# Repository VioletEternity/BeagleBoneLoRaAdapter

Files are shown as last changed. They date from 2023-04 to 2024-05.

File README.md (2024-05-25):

# Dual LoRa module adapter for BeagleBone

This PCBA connects widely available LoRa modules based on Semtech [SX127x][] RFIC, such as [this module][module] ([archive][module-archive]) sold on Aliexpress for less than $3, to the Texas Instruments [BeagleBone][] family of single board computers.

[module]: https://www.aliexpress.com/item/32814250318.html
[module-archive]: https://archive.today/oJ4Fh
[sx127x]: https://www.semtech.com/products/wireless-rf/lora-connect
[beaglebone]: https://beaglebone.org

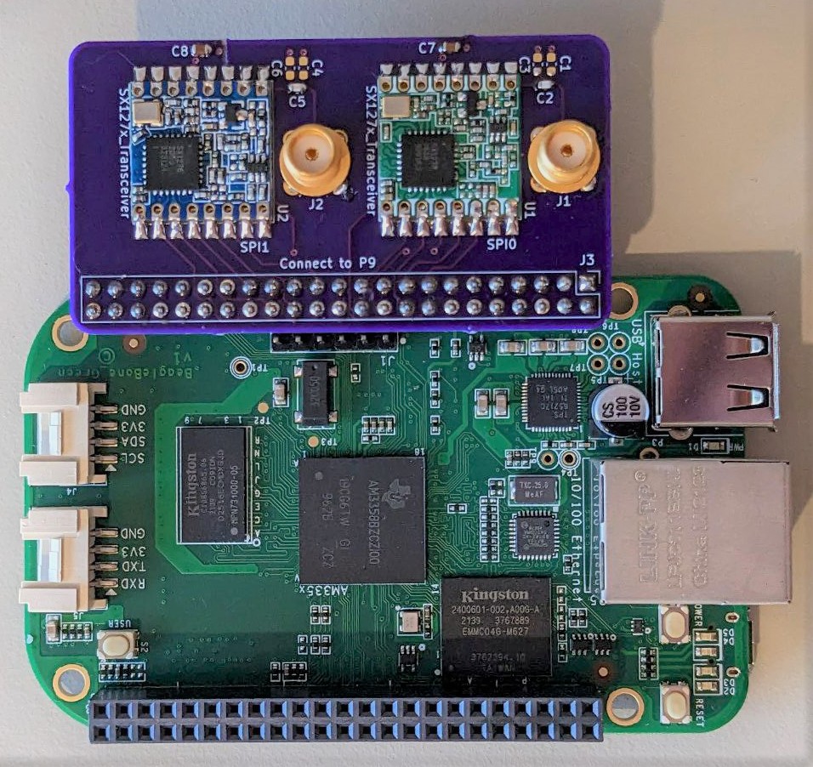
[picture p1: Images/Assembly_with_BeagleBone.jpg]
assembled board


## Requirements

The module must have a size of 16 by 16 mm, and have 16 castellated pads with 2 mm spacing; for details, see the Kicad footprint. The module pinout must match the following, viewed from the top:

| Pin 1? | &nbsp;&nbsp;&nbsp;&nbsp;&nbsp;&nbsp;&nbsp;&nbsp;&nbsp;&nbsp;&nbsp;&nbsp;&nbsp;&nbsp;&nbsp;&nbsp;&nbsp;&nbsp;&nbsp;&nbsp;&nbsp;&nbsp;&nbsp;&nbsp;&nbsp;&nbsp;&nbsp;&nbsp;&nbsp;&nbsp;&nbsp;&nbsp;&nbsp; | &nbsp; |
| --- | - | --- |
| ANT | | GND |
| GND | | DIO5 |
| DIO3 | | nRESET |
| DIO4 | | nCS |
| 3V3 | | SCK |
| DIO0 | | MOSI |
| DIO1 | | MISO |
| DIO2 | | GND |

These modules do not have a clearly marked pin 1, so the actual pinout may be rotated 180° compared to the above.

See also the [bill of materials](Mfg_Outputs/BeagleBoneLoRaAdapter.csv).

## Usage

### BeagleBone pinout

The following table lists the BeagleBone pins and their connections:

| Radio# | Function | BB pin | CPU pin | 
|---|---|---|---|
| radio0 | nRESET | P9_15  | gpio1[16] |
| radio0 | IRQ | P9_16  | gpio1[19] |
| radio0 | nCS | P9_17  | gpio0[5]  |
| radio0 | SCK | P9_22  | gpio0[2]  |
| radio0 | MOSI | P9_18  | gpio0[4]  |
| radio0 | MISO | P9_21  | gpio0[3]  |
| radio1 | nRESET | P9_25  | gpio3[21] |
| radio1 | IRQ | P9_27  | gpio3[19] |
| radio1 | nCS | P9_28  | gpio3[17] |
| radio1 | SCK | P9_31  | gpio3[14] |
| radio1 | MOSI | P9_30  | gpio3[16] |
| radio1 | MISO | P9_29  | gpio3[15] |

Radio 0 is connected to CS0 of SPI0, radio 1 is connected to CS0 of SPI1.

### BeagleBone pin mux configuration

To configure BeagleBone pins, run the following commands:

```shell
sudo modprobe spidev
sudo chown $USER /dev/spidev*

config-pin P9_15 gpio_pu
config-pin P9_16 gpio_pu
config-pin P9_17 spi_cs
config-pin P9_22 spi_sclk
config-pin P9_18 spi
config-pin P9_21 spi

config-pin P9_25 gpio_pu
config-pin P9_27 gpio_pu
config-pin P9_28 spi_cs
config-pin P9_31 spi_sclk
config-pin P9_30 spi
config-pin P9_29 spi
```

These commands were tested on Debian 12 (bookworm).

### Basic functional test

To perform a basic test of module functionality, install `spi-tools` and run the following commands:

```shell
echo '0: 4200' | xxd -r | spi-pipe -b 2 -d /dev/spidev0.0 | xxd
echo '0: 4200' | xxd -r | spi-pipe -b 2 -d /dev/spidev1.0 | xxd
```

Both commands should return the following output:

```
00000000: 0012                                     ..
```

The number `12` is the module ASIC revision.

### Full functional test

Steps for performing a full test of module functionality, including radio transmission and reception, will be provided later.

## Revision history

A1
: Initial revision

## Terms of distribution

The adapter is covered by the CERN-OHL-P (permissive) license. See [LICENSE.txt](LICENSE.txt) for details.

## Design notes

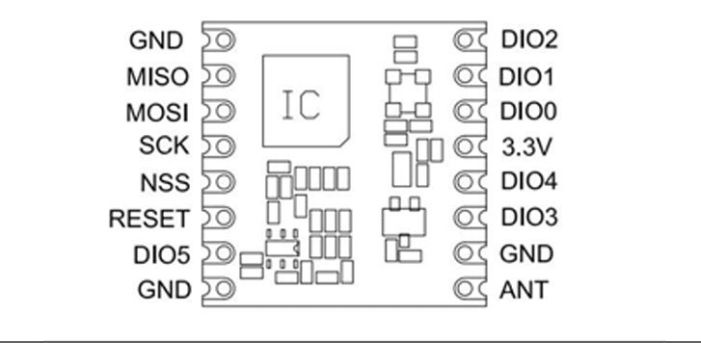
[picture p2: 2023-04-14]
Collateral/SX1278-drawing2.jpg

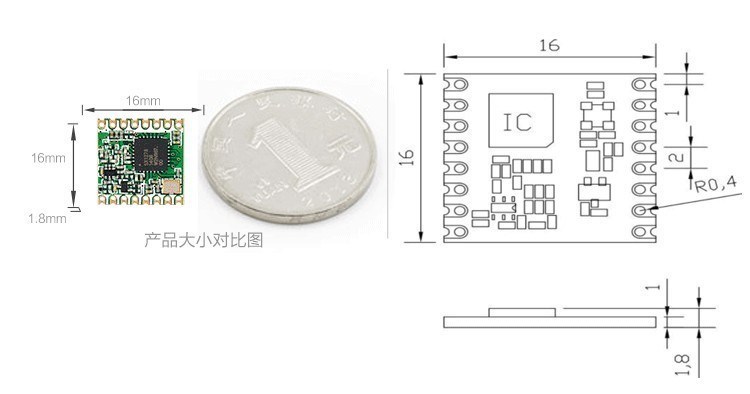
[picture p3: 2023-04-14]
Collateral/SX1278-drawing.jpg

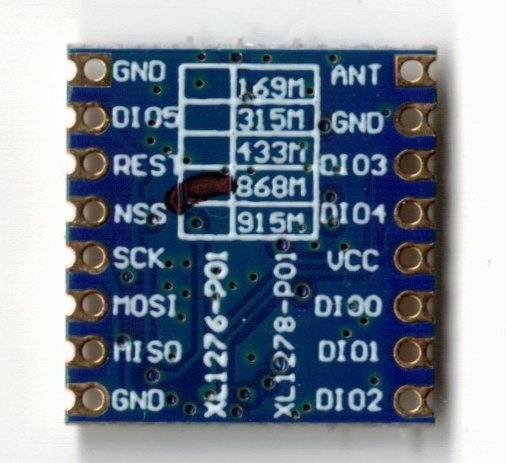
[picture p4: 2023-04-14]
Collateral/XL127x-PO1-868.png

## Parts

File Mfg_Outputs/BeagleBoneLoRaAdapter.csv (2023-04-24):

Reference | Quantity | Value | Footprint | Manufacturer | PartNumber
C1 C3 C4 C6 | 4 | DNP | Capacitor_SMD:C_0603_1608Metric
C2 C5 | 2 | 220p | Capacitor_SMD:C_0603_1608Metric | KEMET | C0603C221J5GACTU
C7 C8 | 2 | 10u | Capacitor_SMD:C_0603_1608Metric | Murata | GRM188R61C106MA73D
J1 J2 | 2 | Conn_Coaxial | Library:SMA_Cinch_142-0701_Vertical | Cinch | 142-0701-201
J3 | 1 | Conn_02x23_Odd_Even | Connector_PinHeader_2.54mm:PinHeader_2x23_P2.54mm_Vertical | Samtec | TSW-125-07-G-D
U1 U2 | 2 | SX127x_Transceiver | Library:LoRaModule-16_16.0x16.0mm_Layout2x8_P2.0mm

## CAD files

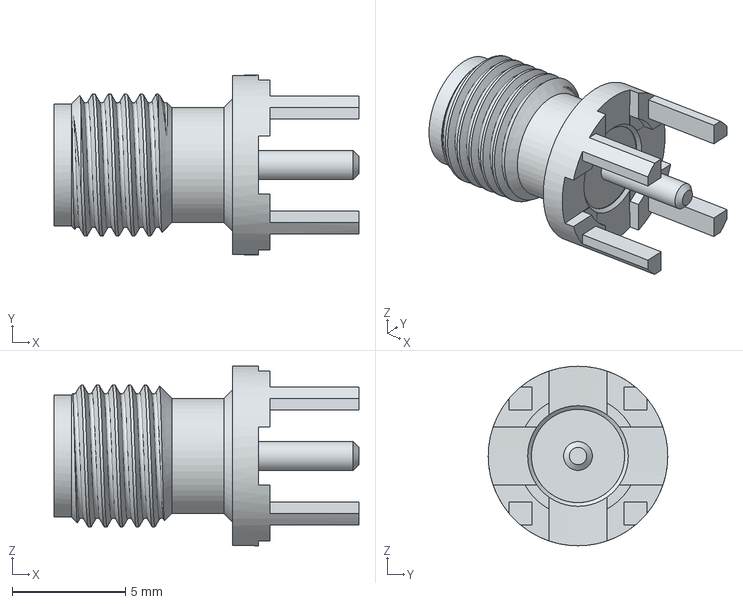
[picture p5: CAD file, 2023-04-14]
3DModels/142-0701-201.stp
13.5 x 7.92 x 7.92 mm

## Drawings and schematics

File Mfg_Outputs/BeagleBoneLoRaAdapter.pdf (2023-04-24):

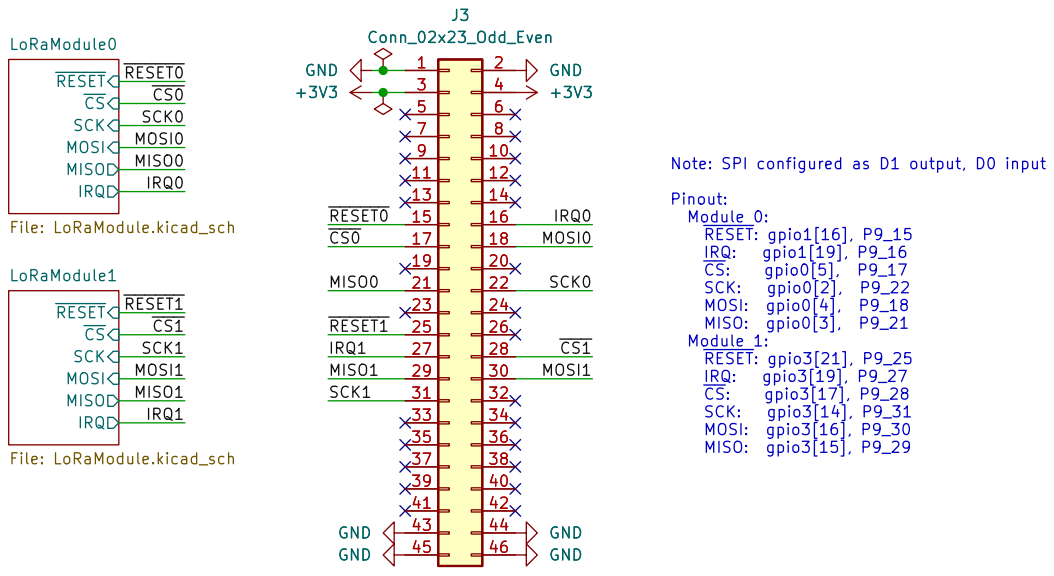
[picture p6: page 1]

File: BeagleBoneLoRaAdapter.kicad_sch Sheet: / Maya

Id: 1/3 Title: BeagleBone to dual LoRa module adapter

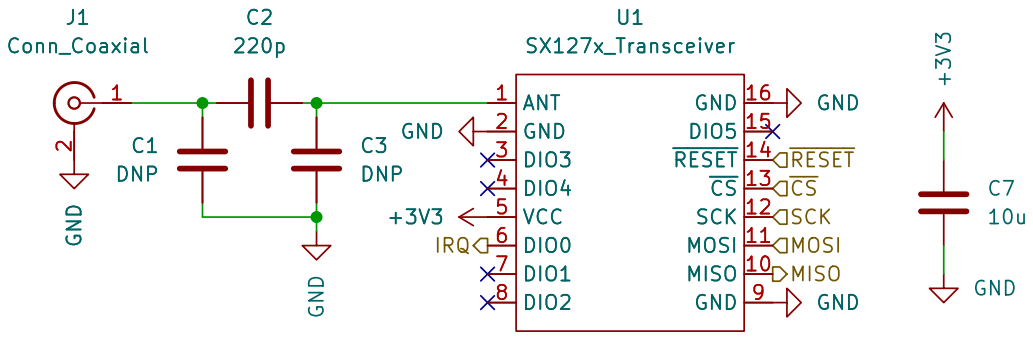
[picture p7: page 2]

~{RESET} MOSI ~{CS} SCK MISO

File: LoRaModule.kicad_sch Sheet: /LoRaModule0/ Maya

Id: 2/3 Title: LoRa module with SMA antenna connector

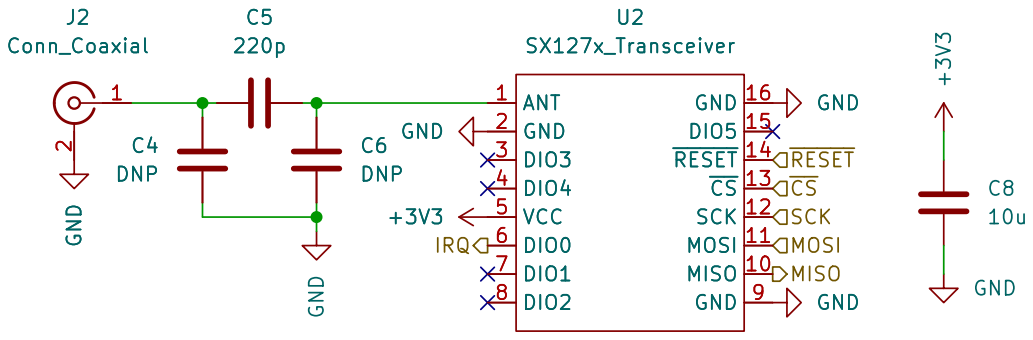
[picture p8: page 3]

2 J2 Conn_Coaxial ANT 1 MISO 10 MOSI 11 SCK 12 ~{CS}13 ~{RESET}14 DIO5 15 GND 16 GND 2 DIO3 3 DIO4 4 VCC 5 DIO0 6 DIO1 7 DIO2 8 GND 9 U2 SX127x_Transceiver C4 DNP GND

~{RESET} MOSI ~{CS} SCK MISO

File: LoRaModule.kicad_sch Sheet: /LoRaModule1/ Maya

Id: 3/3 Title: LoRa module with SMA antenna connector

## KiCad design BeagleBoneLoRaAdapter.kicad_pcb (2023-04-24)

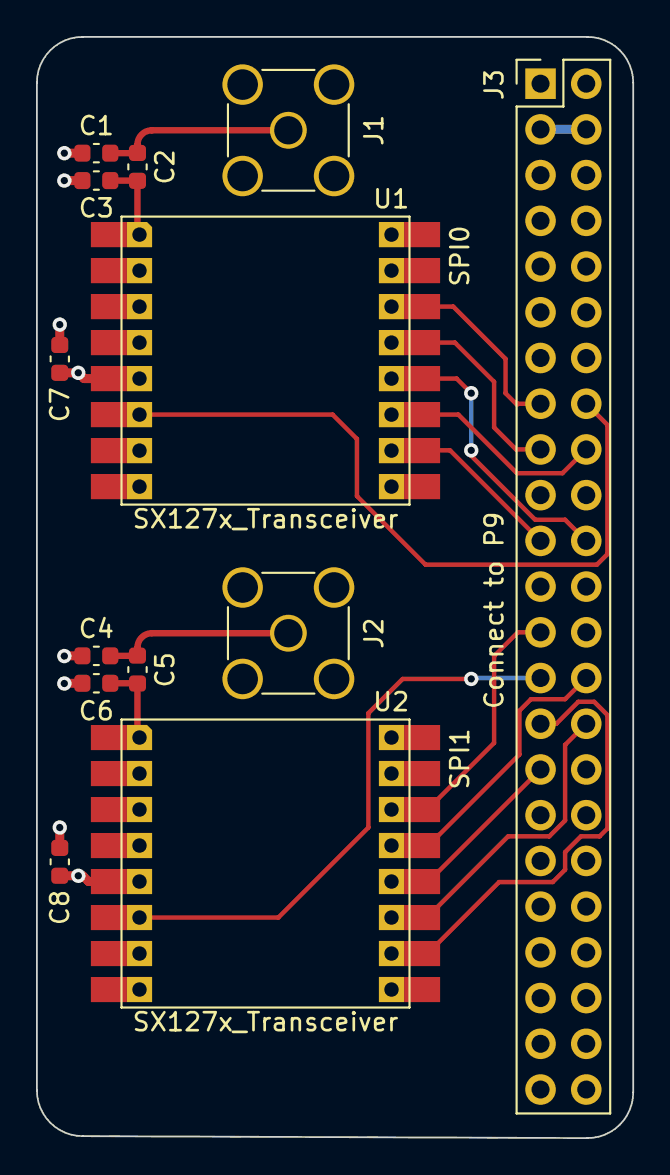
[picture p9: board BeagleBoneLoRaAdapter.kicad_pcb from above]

Board: 4 copper layers, 33.1 x 61.2 mm, 13 parts (0 on the bottom side), 18 nets.

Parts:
C1, C3, C4, C6: DNP; C_0603_1608Metric
C2, C5: 220p; C_0603_1608Metric
C7, C8: 10u; C_0603_1608Metric
J1, J2: Conn_Coaxial; SMA_Cinch_142-0701_Vertical
J3: Conn_02x23_Odd_Even; PinHeader_2x23_P2.54mm_Vertical
U1, U2: SX127x_Transceiver; LoRaModule-16_16.0x16.0mm_Layout2x8_P2.0mm

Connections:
+3V3: C7.1, C8.1, J3.3, J3.4, U1.5 (VCC), U2.5 (VCC)
/IRQ0: J3.16, U1.6 (DIO0)
/IRQ1: J3.27, U2.6 (DIO0)
/MISO0: J3.21, U1.10 (MISO)
/MISO1: J3.29, U2.10 (MISO)
/MOSI0: J3.18, U1.11 (MOSI)
/MOSI1: J3.30, U2.11 (MOSI)
/SCK0: J3.22, U1.12 (SCK)
/SCK1: J3.31, U2.12 (SCK)
/~CS0: J3.17, U1.13 (~CS)
/~CS1: J3.28, U2.13 (~CS)
/~RESET0: J3.15, U1.14 (~RESET)
/~RESET1: J3.25, U2.14 (~RESET)
GND: C1.1, C3.2, C4.1, C6.2, C7.2, C8.2, J1.2 (Ext), J2.2 (Ext), J3.1, J3.2, J3.43, J3.44, J3.45, J3.46, U1.2 (GND), U1.9 (GND), U1.16 (GND), U2.2 (GND), U2.9 (GND), U2.16 (GND)
unnamed: C1.2, C2.1, J1.1 (In)
unnamed: C2.2, C3.1, U1.1 (ANT)
unnamed: C4.2, C5.1, J2.1 (In)
unnamed: C5.2, C6.1, U2.1 (ANT)

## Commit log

2023-04-14 Rev A1
    [142-0701-201.stp, BeagleBoneLoRaAdapter.kicad_pcb, BeagleBoneLoRaAdapter.kicad_sch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]
2023-04-24 Add Px_y pin names on schematic
    [BeagleBoneLoRaAdapter.kicad_sch]
2023-04-24 Add schematic to mfg outputs
2023-04-24 Reexport gerbers with solder mask substracted from silk
    [BeagleBoneLoRaAdapter.kicad_pcb]
2023-04-24 Add BOM
    [BeagleBoneLoRaAdapter.csv, BeagleBoneLoRaAdapter.kicad_pcb, BeagleBoneLoRaAdapter.kicad_sch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]
